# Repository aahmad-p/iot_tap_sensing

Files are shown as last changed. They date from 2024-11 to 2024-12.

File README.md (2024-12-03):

# _flomon_: A Water Tap Monitoring IoT System
This repository contains code and CAD (electrical and mechanical) files for _flomon_. This is a brief summary of the contents (by folder):
- ECAD: Contains electrical schematic and PCB layout files for custom sensor module (utilizing nRF52805 SoC for Bluetooth connectivity).
- Firmware: Contains firmware for sensor module (written in _C_).
- Gateway: Contains code for gateway (Raspberry Pi) interfacing with AWS IoT Core (written in _python_) .
- MCAD: Contains mechanical drawings for custom gateway and sensor housings (including custom adapter fittings).

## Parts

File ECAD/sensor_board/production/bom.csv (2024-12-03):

Comment | Designator | Footprint | LCSC Part Number
12pF C0G | C10, C9 | 402 | C1547
10uF | C11 | 805 | C15850
100nF | C2, C3 | 603 | C14663
5V | D1 | D_SOD-323 | C552583
S4B-XH-SM4-TB | J4 | CONN4_S4B-XH_JST | C161861
PMV48XP | Q2, Q3 | SOT-23 | C2959854
2N7002 | Q4 | SOT-23 | C916396
10R | R1 | 603 | C22859
100k | R12, R13 | 603 | C25803
330k | R2, R9 | 603 | C100970
22k | R6, R7 | 603 | C31850
TPL5111 | U1 | SOT-23-6 | C2870554
TPS22917DBV | U2 | SOT-23-6 | C2681320
32.768kHz | Y1 | Crystal_SMD_3215-2Pin_3.2x1.5mm | C32346

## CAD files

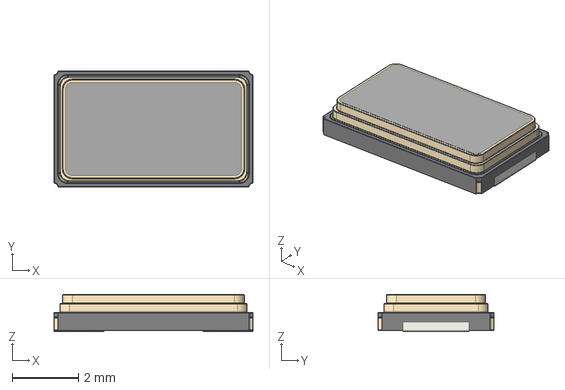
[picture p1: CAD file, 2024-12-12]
ECAD/sensor_board/3D/Crystal_SMD_0603-2Pin_6.0x3.5mm.step
6.00 x 3.50 x 1.13 mm

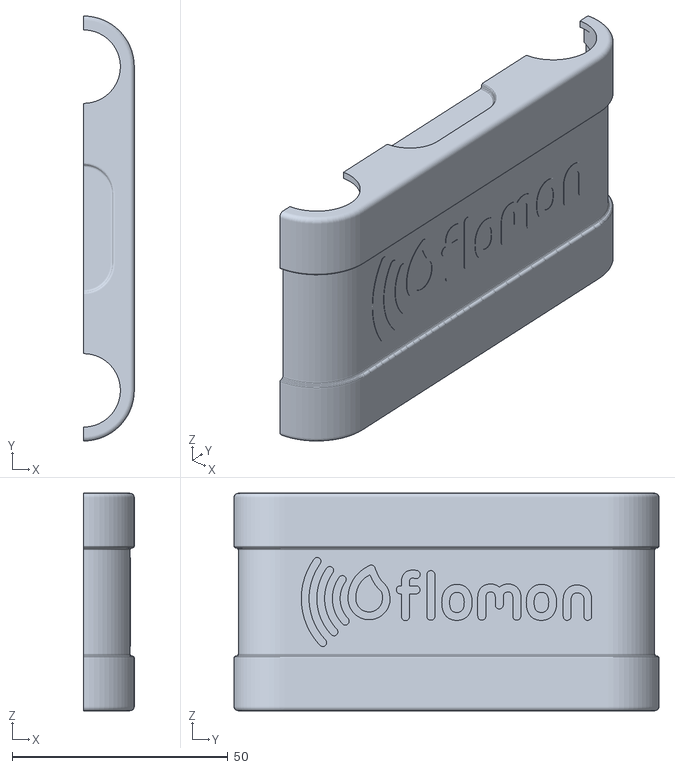
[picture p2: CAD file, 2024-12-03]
MCAD/FM-001A-Sensor-Top.stl
11.7 x 98.5 x 50.4

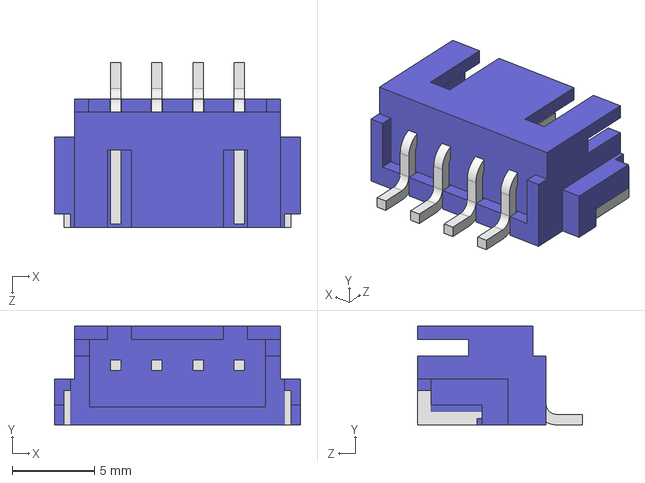
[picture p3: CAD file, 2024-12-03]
ECAD/sensor_board/3D/S4B-XH-SM4-TB.STEP
15.0 x 6.00 x 10.0 mm

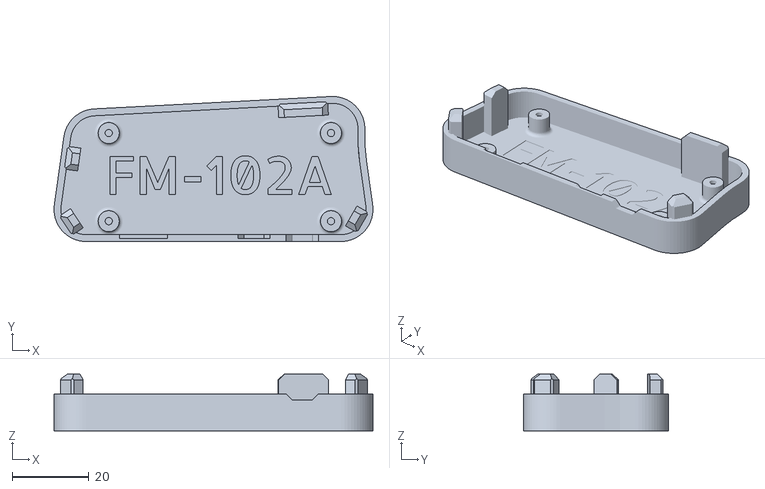
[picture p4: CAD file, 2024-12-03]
MCAD/FM-102A-Gateway-Bottom.stl
83.2 x 37.8 x 14.8

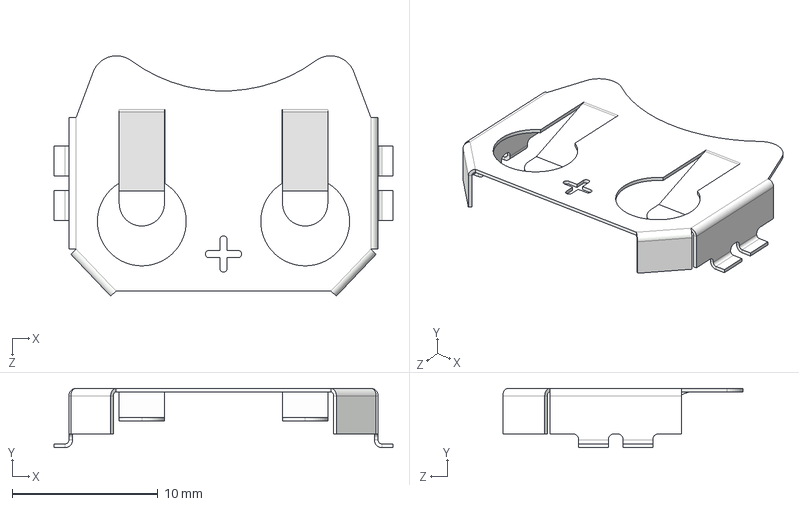
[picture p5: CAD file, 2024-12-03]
ECAD/sensor_board/3D/3034.step
23.2 x 4.06 x 16.5 mm

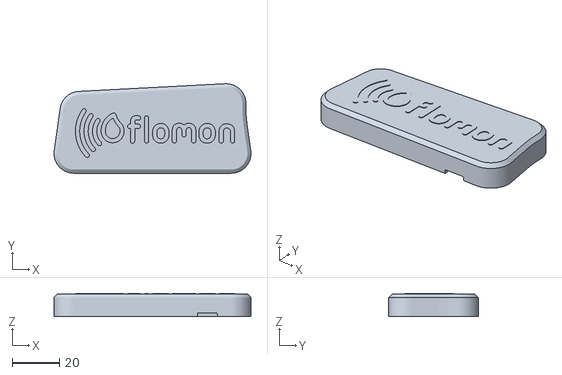
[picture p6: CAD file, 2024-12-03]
MCAD/FM-101A-Gateway-Top.stl
83.2 x 37.8 x 9.83

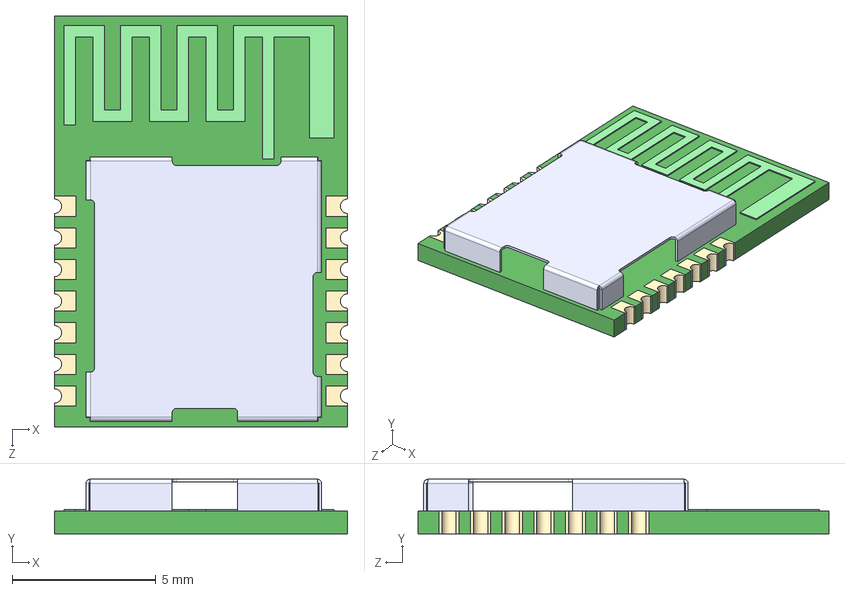
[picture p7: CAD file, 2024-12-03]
ECAD/sensor_board/3D/BC805M--3DModel-STEP-56544.STEP
10.2 x 1.90 x 14.3 mm

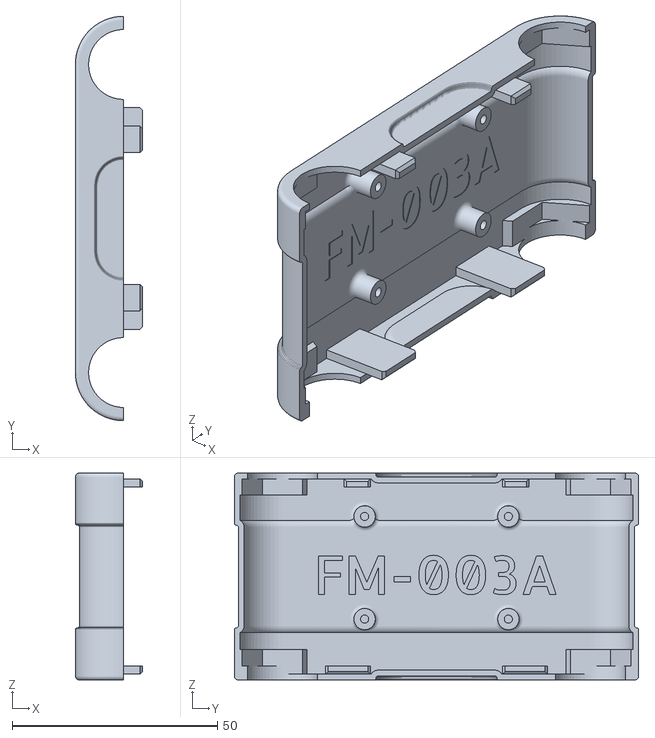
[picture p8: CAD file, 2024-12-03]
MCAD/FM-003A-Sensor-Bottom.stl
16.4 x 98.5 x 50.4

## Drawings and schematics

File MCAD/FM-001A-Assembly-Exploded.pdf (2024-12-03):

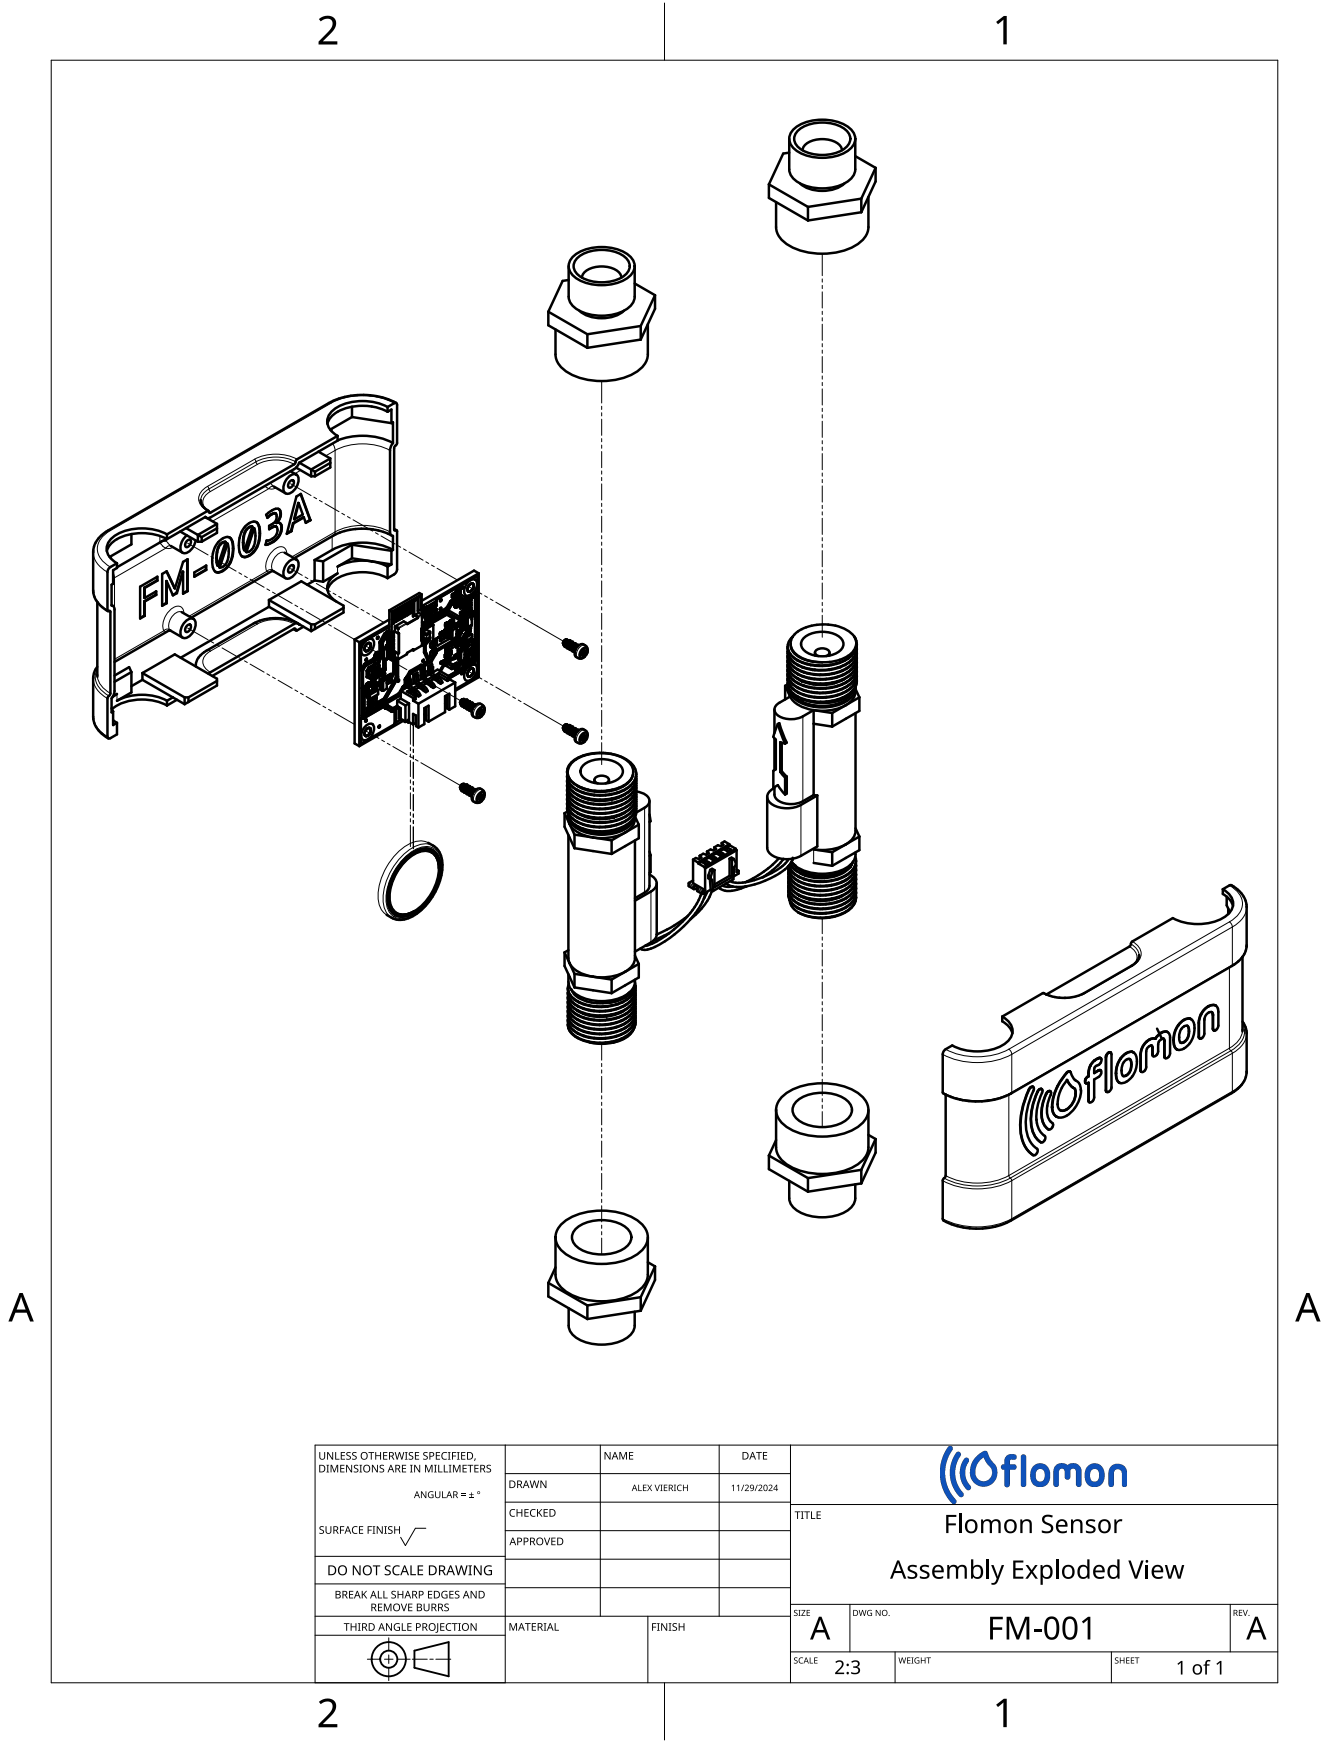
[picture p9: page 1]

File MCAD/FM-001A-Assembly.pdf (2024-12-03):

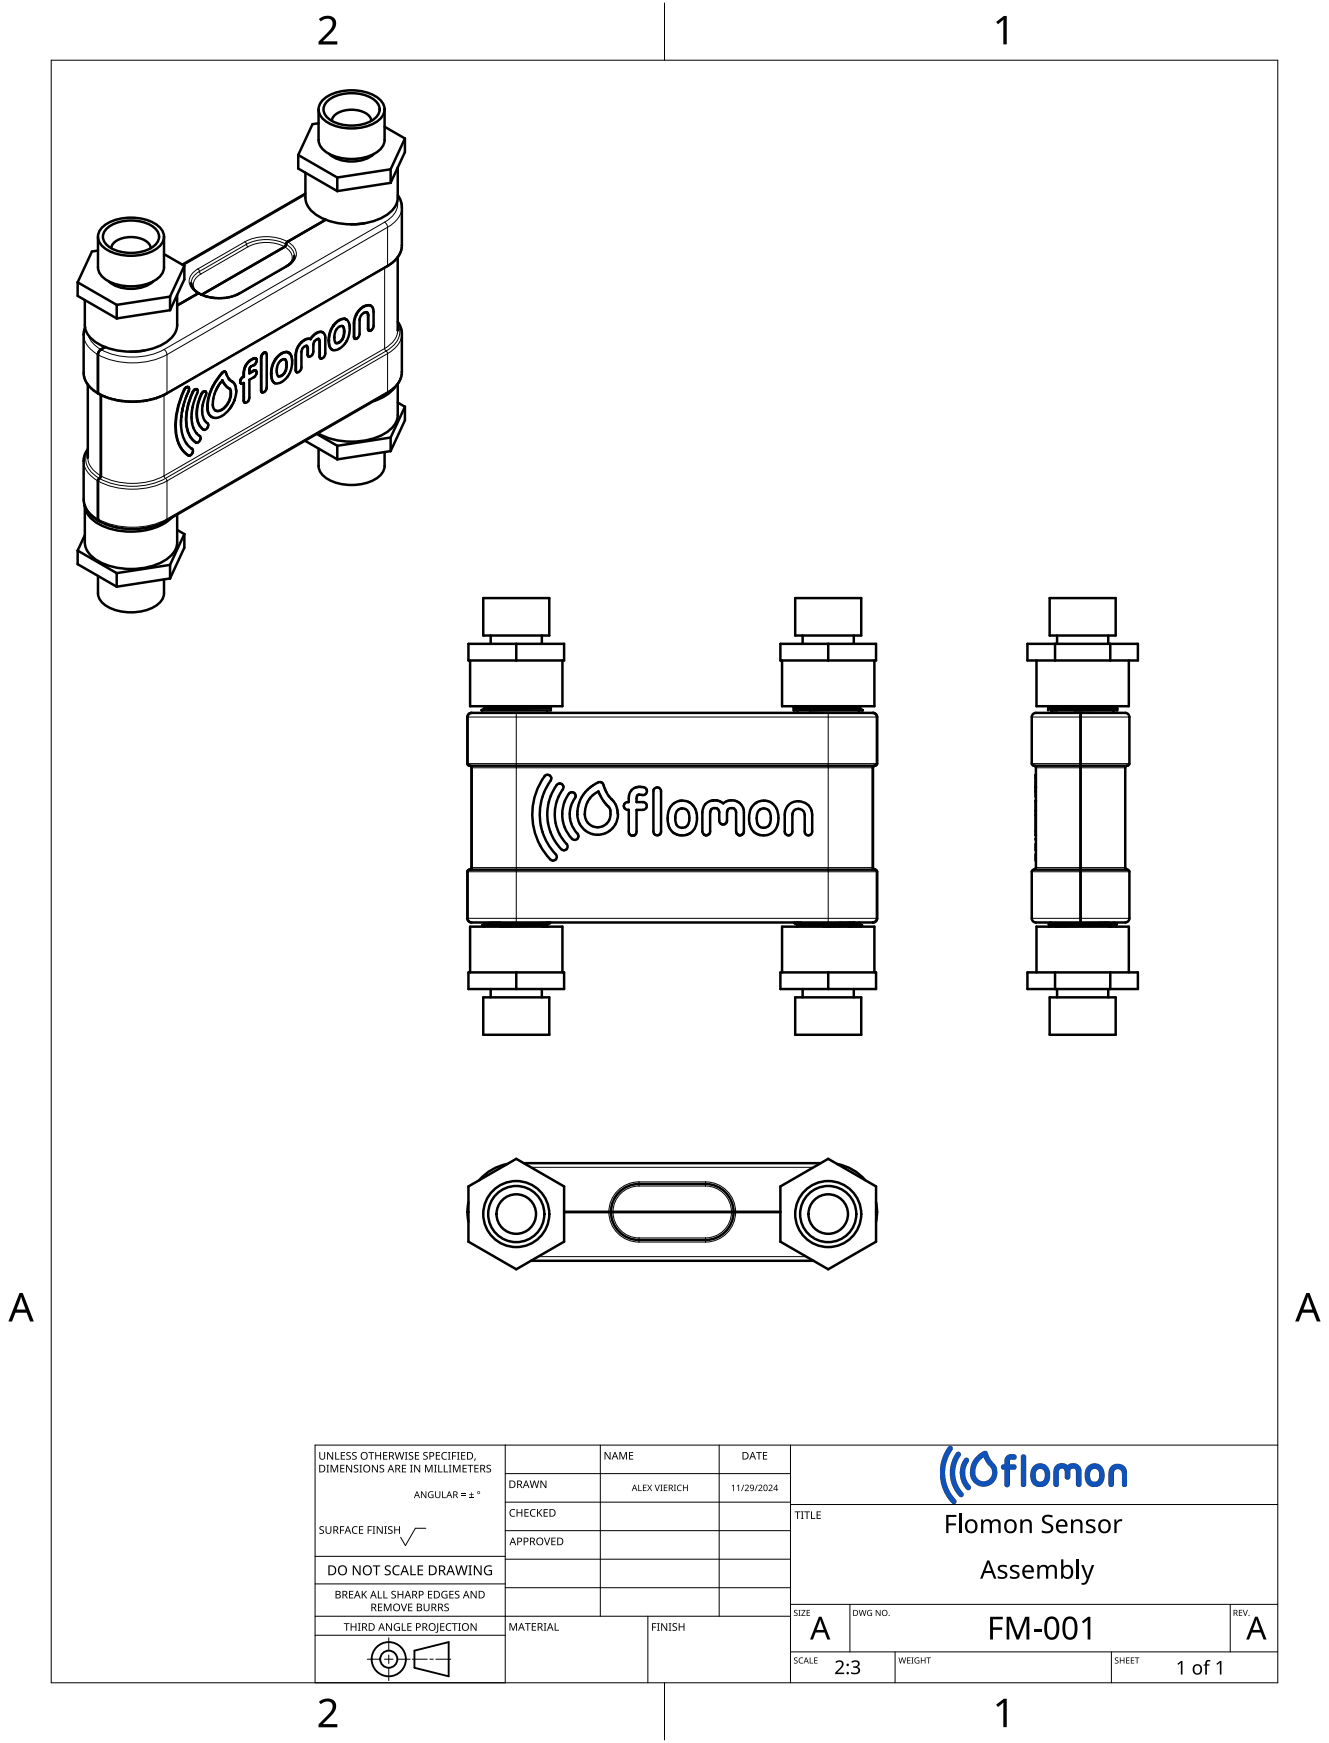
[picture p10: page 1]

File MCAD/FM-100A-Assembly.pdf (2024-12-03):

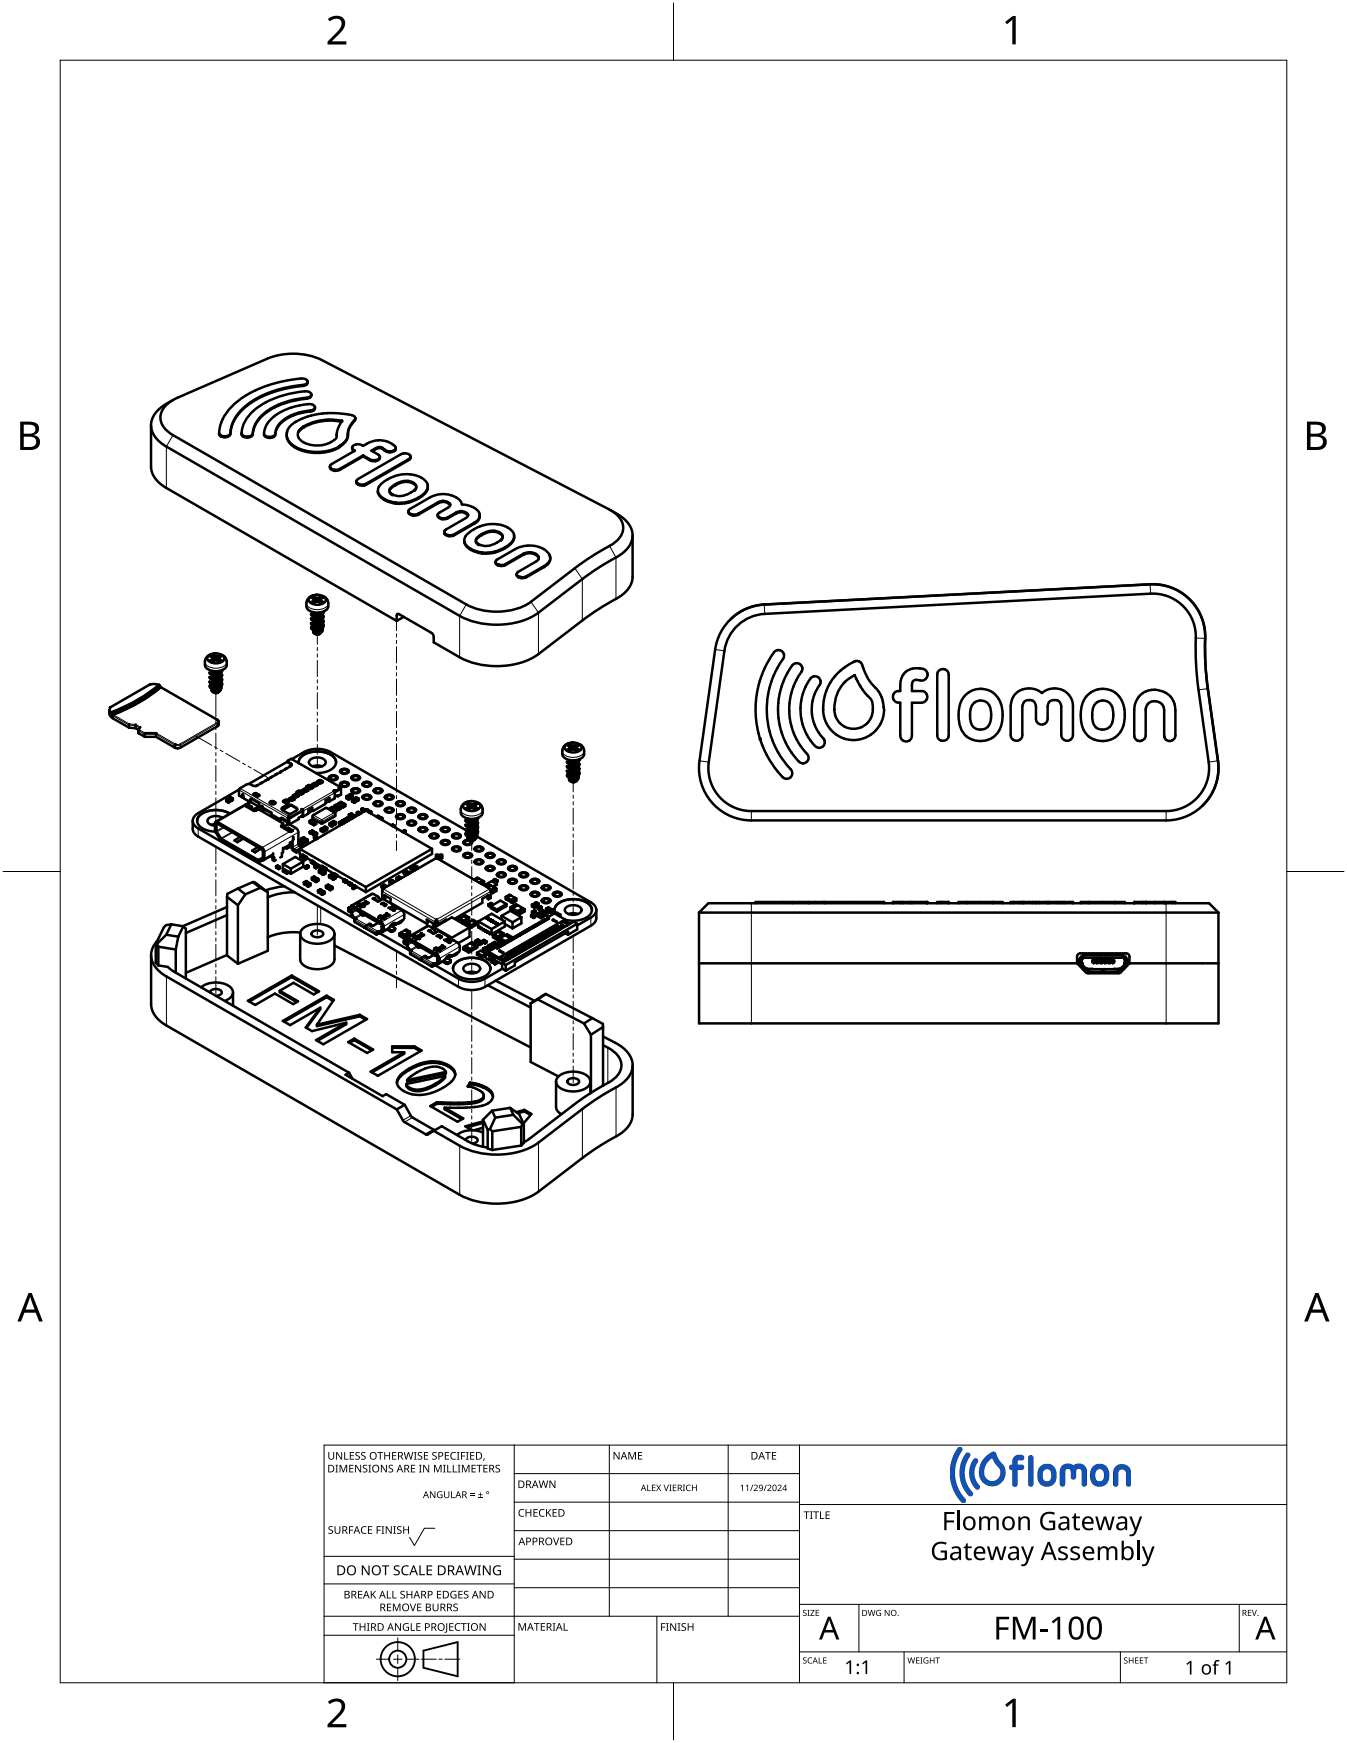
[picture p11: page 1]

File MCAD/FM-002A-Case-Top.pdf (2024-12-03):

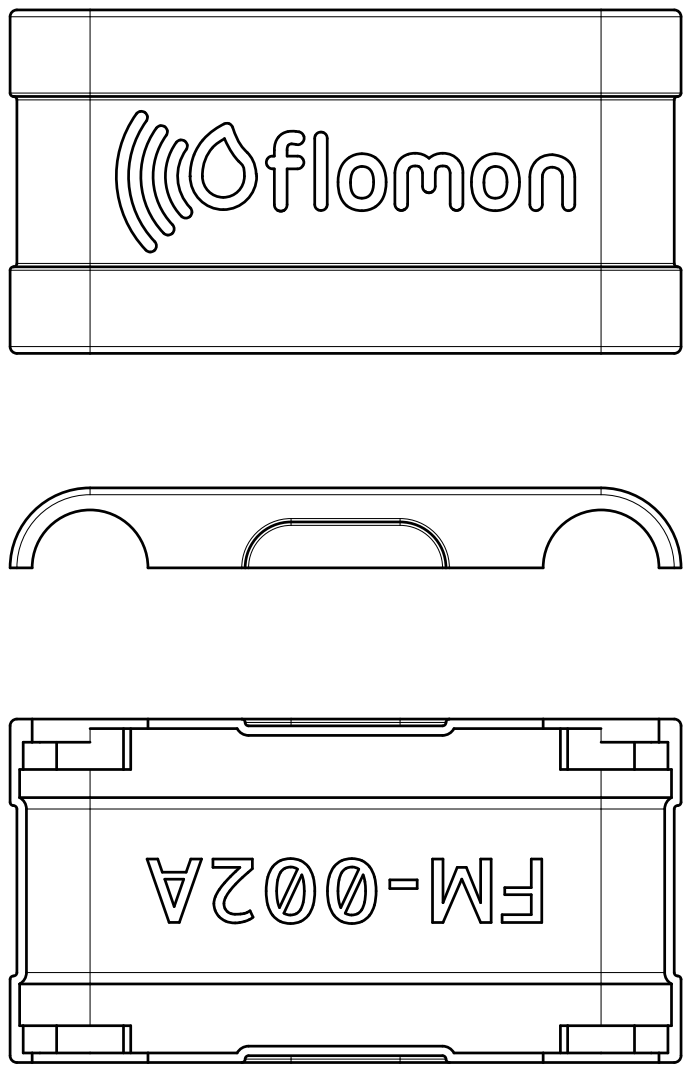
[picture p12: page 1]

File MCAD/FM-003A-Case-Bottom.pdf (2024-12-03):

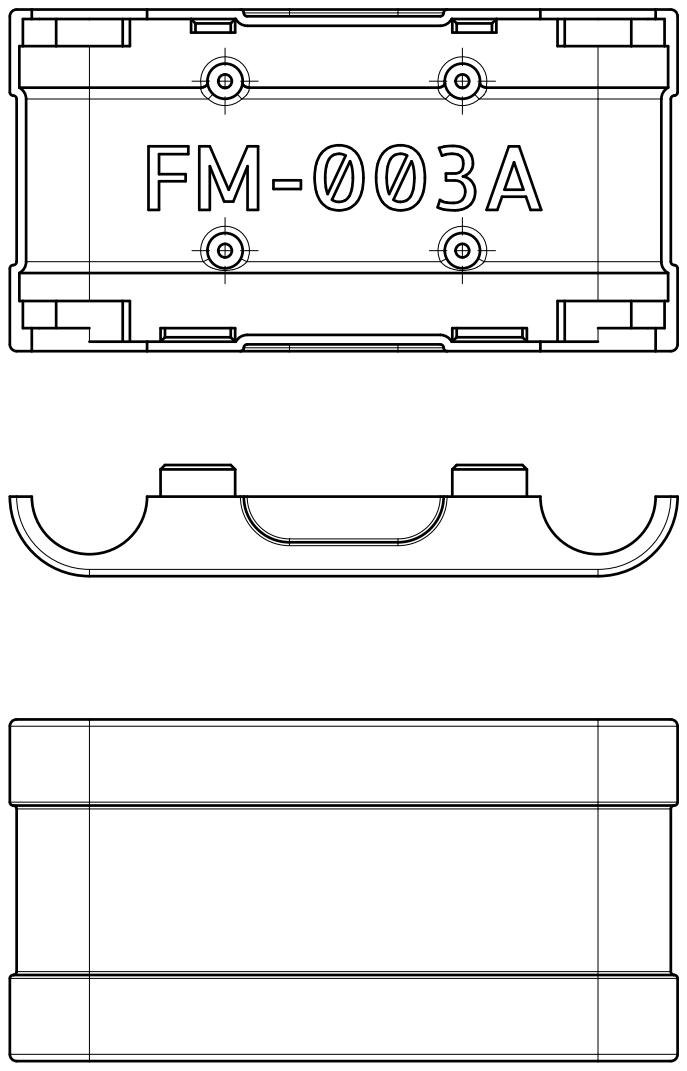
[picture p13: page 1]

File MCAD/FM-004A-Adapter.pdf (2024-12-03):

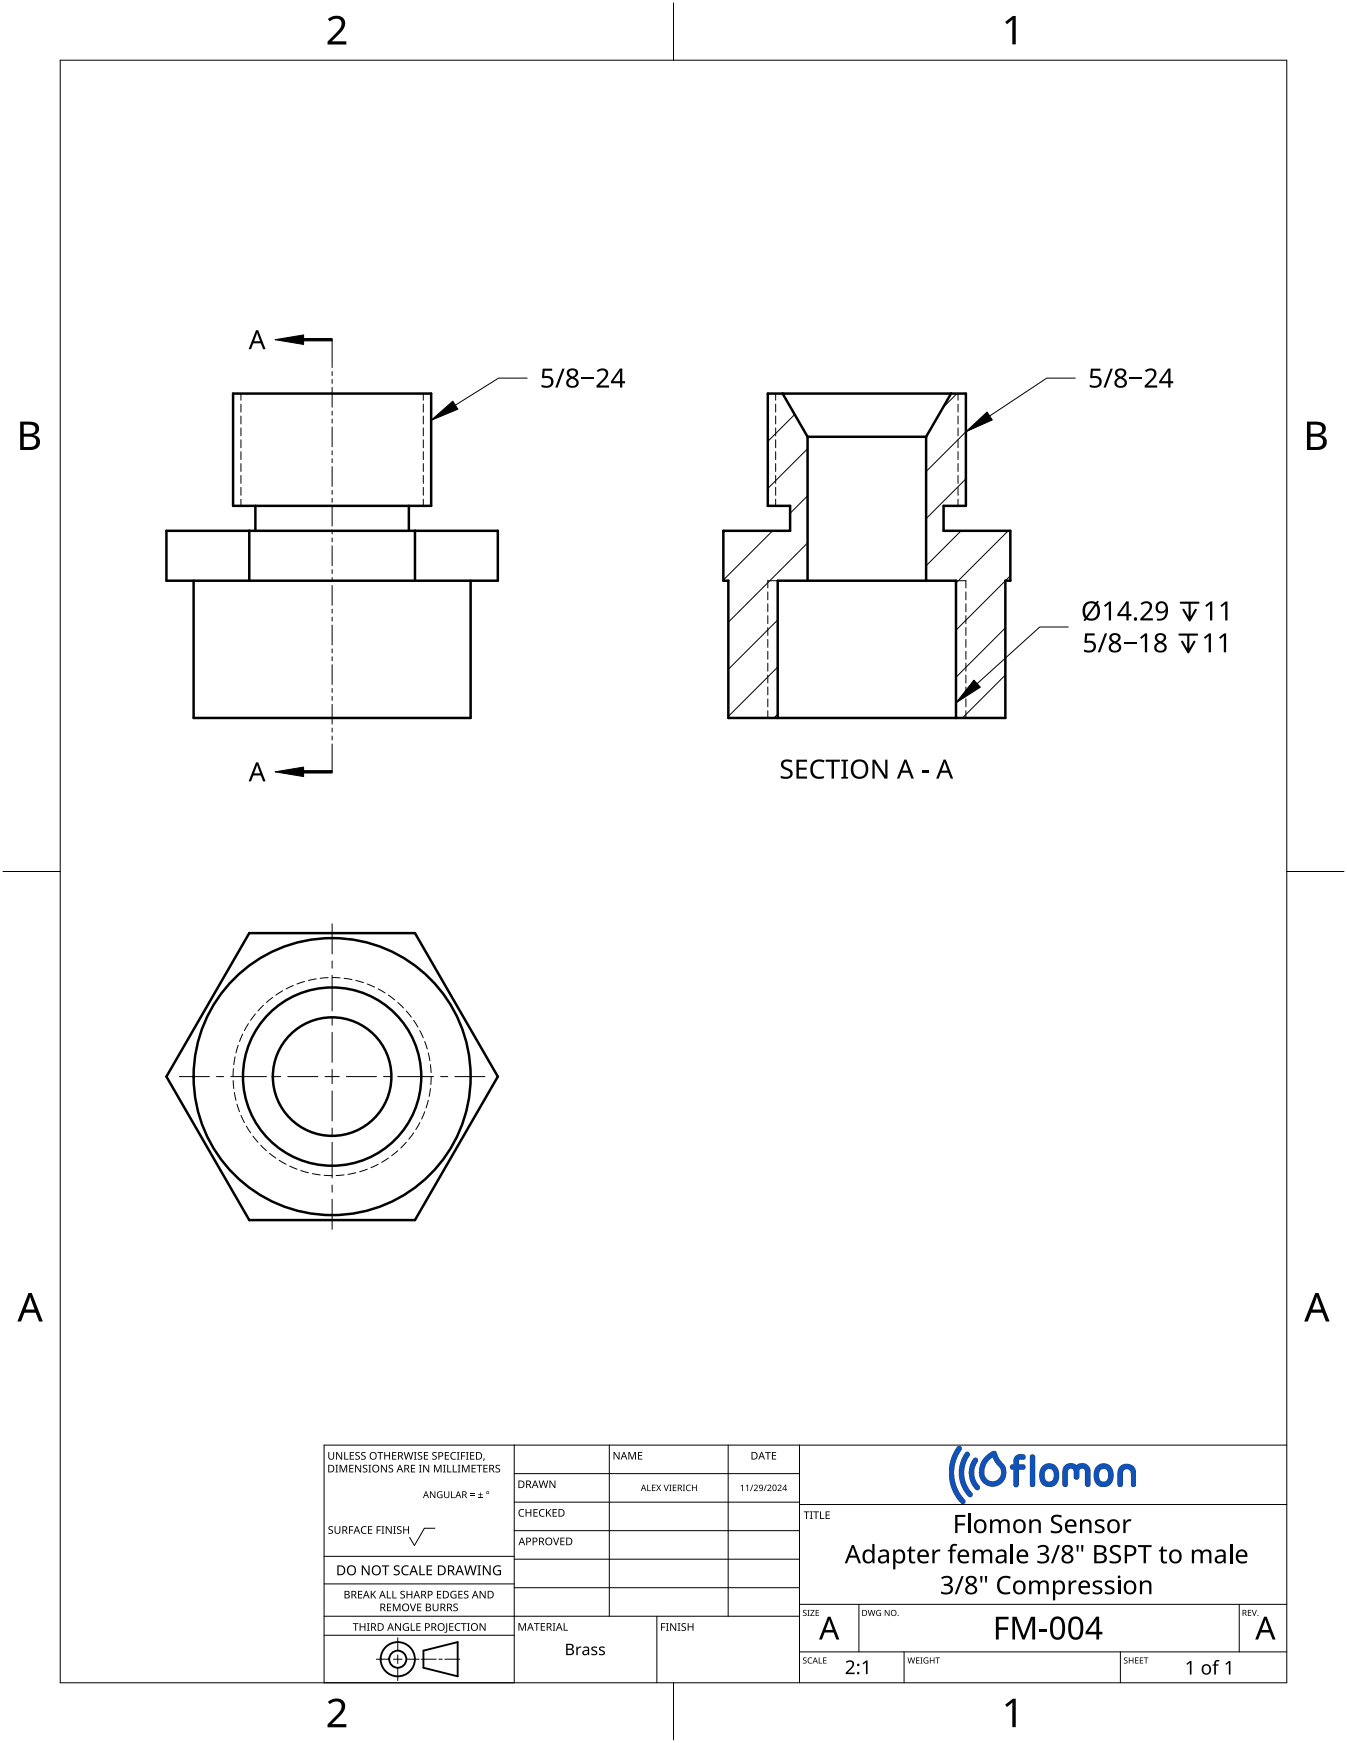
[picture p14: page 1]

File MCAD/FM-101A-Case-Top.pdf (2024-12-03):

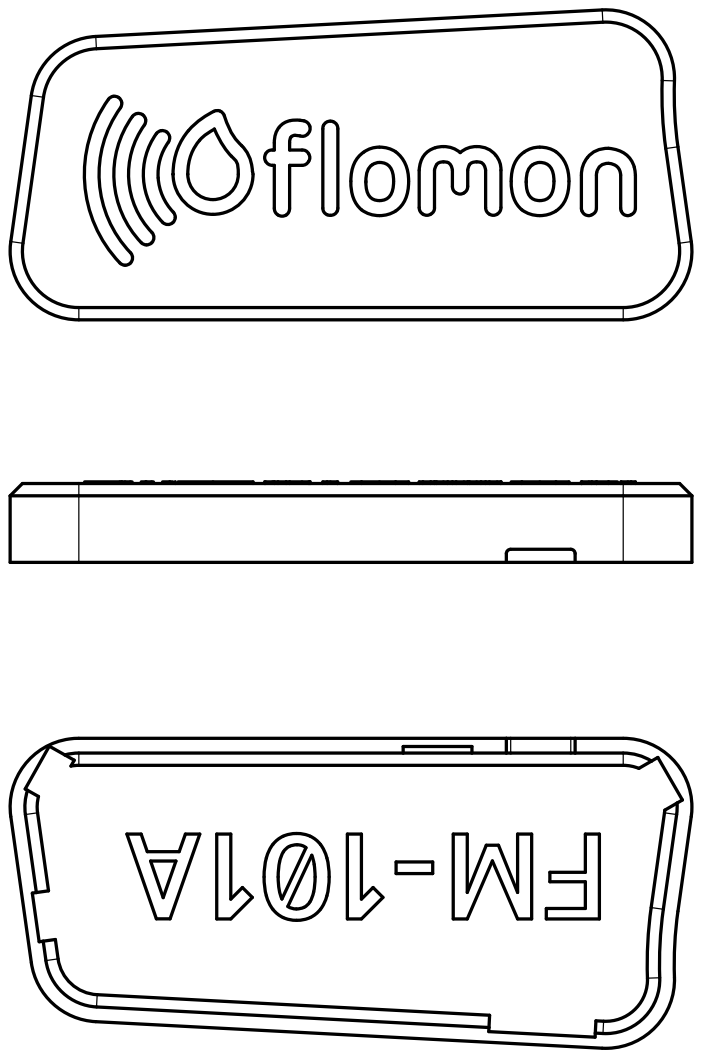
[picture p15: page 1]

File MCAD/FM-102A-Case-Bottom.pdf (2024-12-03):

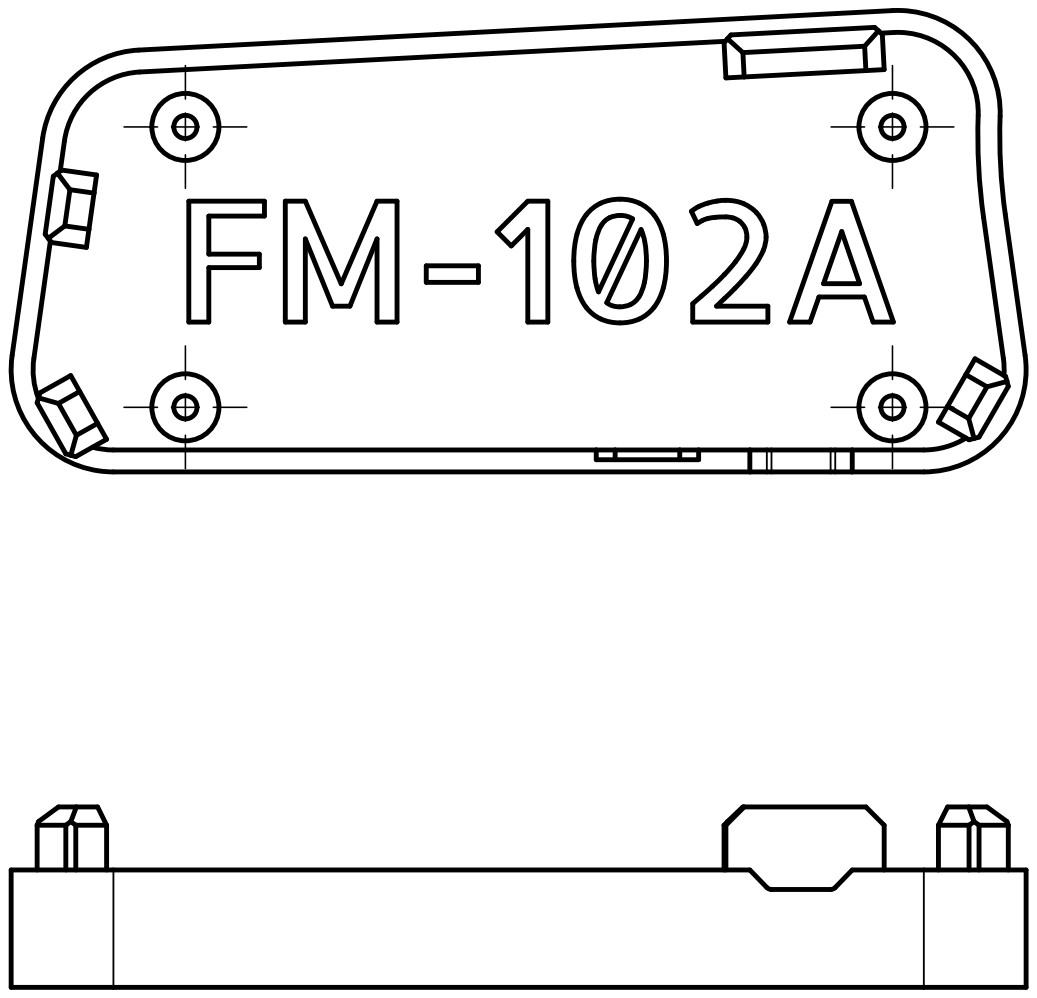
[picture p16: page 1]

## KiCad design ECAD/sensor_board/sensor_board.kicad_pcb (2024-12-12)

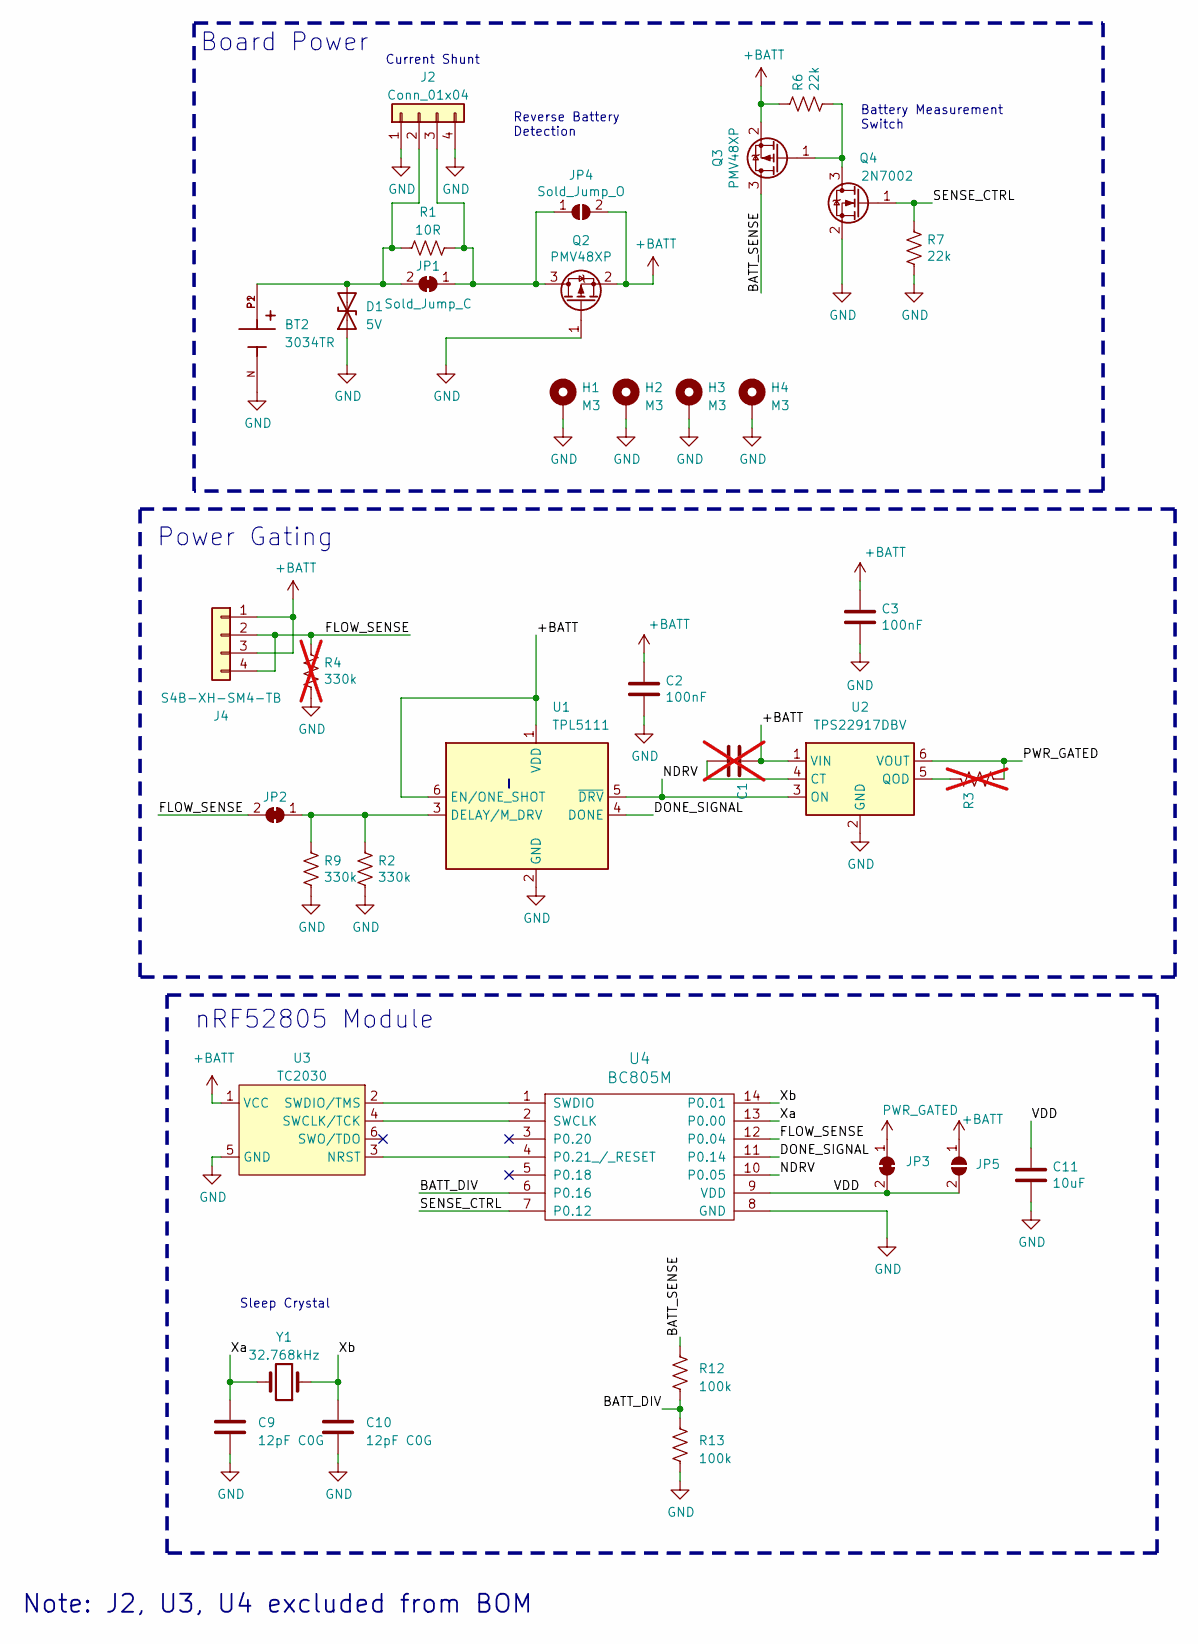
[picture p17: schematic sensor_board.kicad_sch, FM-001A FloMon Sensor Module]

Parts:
BT2: 3034TR; BAT_3034TR; PARTREV E; JLC C5213768
C1: C_0603_1608Metric; not fitted
C2, C3: 100nF; C_0603_1608Metric; MPN CC0603KRX7R9BB104; JLC C14663
C9, C10: 12pF C0G; C_0402_1005Metric; MPN 0402CG120J500NT; JLC C1547
C11: 10uF; C_0805_2012Metric; MPN CL21A106KAYNNNE; JLC C15850
D1: 5V; D_SOD-323; MPN PESD5V0V1BA,115; JLC C552583
H1, H2, H3, H4: M3; MountingHole_2.2mm_M2_Pad
J2: Conn_01x04; Test_Wire_Pad_x4
J4: S4B-XH-SM4-TB; CONN4_S4B-XH_JST; JLC C161861
JP1: Sold_Jump_C; SolderJumper-2_P1.3mm_Bridged_RoundedPad1.0x1.5mm
JP2, JP3: SolderJumper-2_P1.3mm_Bridged_RoundedPad1.0x1.5mm
JP4: Sold_Jump_O; SolderJumper-2_P1.3mm_Open_RoundedPad1.0x1.5mm
JP5: SolderJumper-2_P1.3mm_Open_RoundedPad1.0x1.5mm
Q2, Q3: PMV48XP; SOT-23; MPN PMV48XP; JLC C2959854
Q4: 2N7002; SOT-23; JLC C916396
R1: 10R; R_0603_1608Metric; MPN 0603WAF100JT5E; JLC C22859
R2, R9: 330k; R_0603_1608Metric; MPN CR0603FA3303G; JLC C100970
R3: R_0603_1608Metric; not fitted
R4: 330k; R_0603_1608Metric; MPN CR0603FA3303G; JLC C100970; not fitted
R6, R7: 22k; R_0603_1608Metric; MPN 0603WAF2202T5E; JLC C31850
R12, R13: 100k; R_0603_1608Metric; MPN 0603WAF1003T5E; JLC C25803
U1: TPL5111; SOT-23-6; JLC C2870554
U2: TPS22917DBV; SOT-23-6; JLC C2681320
U3: TC2030; TC2030-IDC-NL
U4: BC805M; BC805M_No_Paste
Y1: 32.768kHz; Crystal_SMD_3215-2Pin_3.2x1.5mm; MPN Q13FC1350000400; JLC C32346

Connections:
+BATT: C1.1, C2.1, C3.1, J4.1, J4.3, JP4.2 (B), JP5.1 (A), Q2.2 (S), Q3.2 (S), R6.1, U1.1 (VDD), U1.6 (EN/ONE_SHOT), U2.1 (VIN), U3.1 (VCC)
/BATT_DIV: R12.2, R13.1, U4.6 (P0.16)
/BATT_SENSE: Q3.3 (D), R12.1
/DONE_SIGNAL: U1.4 (DONE), U4.11 (P0.14)
/FLOW_SENSE: J4.2, J4.4, JP2.2 (B), R4.1, U4.12 (P0.04)
/NDRV: U1.5 (~DRV), U2.3 (ON), U4.10 (P0.05)
/SENSE_CTRL: Q4.1 (G), R7.1, U4.7 (P0.12)
/VDD: C11.1, JP3.2 (B), JP5.2 (B), U4.9 (VDD)
/Xa: C9.2, U4.13 (P0.00), Y1.2
/Xb: C10.2, U4.14 (P0.01), Y1.1
GND: BT2.N, C2.2, C3.2, C9.1, C10.1, C11.2, D1.1 (A1), H1.1, H2.1, H3.1, H4.1, J2.1, J2.4, Q2.1 (G), Q4.2 (S), R2.2, R4.2, R7.2, R9.2, R13.2, U1.2 (GND), U2.2 (GND), U3.5 (GND), U4.8 (GND)
unnamed: BT2.P1, BT2.P2, D1.2 (A2), J2.2, JP1.2 (B), R1.1
unnamed: J2.3, JP1.1 (A), JP4.1 (A), Q2.3 (D), R1.2
unnamed: JP2.1 (A), R2.1, R9.1, U1.3 (DELAY/M_DRV)
unnamed: Q3.1 (G), Q4.3 (D), R6.2
unnamed: C1.2, U2.4 (CT)
unnamed: R3.1, U2.5 (QOD)
unnamed: U3.3 (NRST), U4.4 (P0.21_/_RESET)
unnamed: U3.4 (SWCLK/TCK), U4.2 (SWCLK)
unnamed: U3.2 (SWDIO/TMS), U4.1 (SWDIO)
PWR_GATED: JP3.1 (A), R3.2, U2.6 (VOUT)

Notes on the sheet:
Power Gating
Battery Measurement Switch
Sleep Crystal
Note: J2, U3, U4 excluded from BOM
Current Shunt
Board Power
Reverse Battery Detection
nRF52805 Module

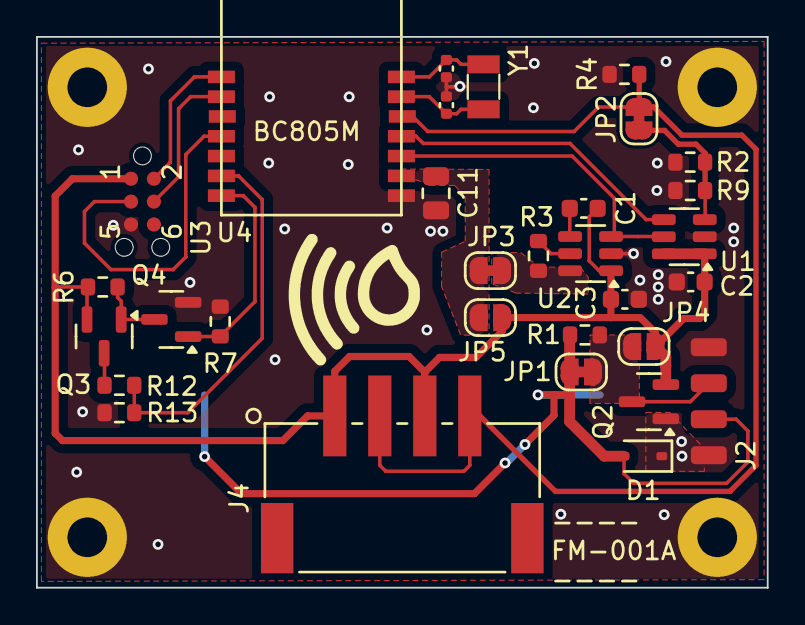
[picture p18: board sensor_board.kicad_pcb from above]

Board: 2 copper layers, 40.6 x 30.6 mm, 36 parts (1 on the bottom side), 21 nets.

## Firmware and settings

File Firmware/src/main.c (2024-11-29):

/*
 * Copyright (c) 2023 Nordic Semiconductor ASA
 *
 * SPDX-License-Identifier: Apache-2.0
 */

#include <zephyr/bluetooth/bluetooth.h>
#include <zephyr/bluetooth/uuid.h>
#include <zephyr/drivers/gpio.h>

#define SERVICE_DATA_LEN        7
#define SERVICE_UUID            0xfcd2      /* BTHome service UUID */
#define IDX_RUNNING               4           /* Index of byte of running in service data*/
#define IDX_WATCHDOG              6           /* Index of byte of watchdog in service data*/

#define ADV_PARAM BT_LE_ADV_PARAM(BT_LE_ADV_OPT_USE_IDENTITY, \
				  BT_GAP_ADV_SLOW_INT_MIN, \
				  BT_GAP_ADV_SLOW_INT_MAX, NULL)


#define MAX_OFF_PERIODS           20 

static const struct gpio_dt_spec pm_done = GPIO_DT_SPEC_GET(DT_NODELABEL(pm_done), gpios);
static const struct gpio_dt_spec button = GPIO_DT_SPEC_GET(DT_NODELABEL(button), gpios);


static uint8_t service_data[SERVICE_DATA_LEN] = {
	BT_UUID_16_ENCODE(SERVICE_UUID),
	0x40,
	0x27,	/* Running */
	0x00,	/* Off Byte */
	0x0F,   /* Generic Boolean (watchdog) */
	0x00    /* Watchdog Byte */
};

static struct bt_data ad[] = {
	BT_DATA_BYTES(BT_DATA_FLAGS, BT_LE_AD_GENERAL | BT_LE_AD_NO_BREDR),
	BT_DATA(BT_DATA_NAME_COMPLETE, CONFIG_BT_DEVICE_NAME, sizeof(CONFIG_BT_DEVICE_NAME) - 1),
	BT_DATA(BT_DATA_SVC_DATA16, service_data, ARRAY_SIZE(service_data))
};

static void bt_ready(int err)
{
	if (err) {
		printk("Bluetooth init failed (err %d)\n", err);
		return;
	}

	printk("Bluetooth initialized\n");

	/* Start advertising */
	err = bt_le_adv_start(ADV_PARAM, ad, ARRAY_SIZE(ad), NULL, 0);
	if (err) {
		printk("Advertising failed to start (err %d)\n", err);
		return;
	}
}

int main(void)
{
	int err;
	int ret;
	int off_periods = 0;

	printk("Sensor Starting\n");

	/* Initialize Peripherals */

	if(!device_is_ready(button.port)){
		return 0;
	}

	/* Initialize the Bluetooth Subsystem */
	err = bt_enable(bt_ready);
	if (err) {
		printk("Bluetooth init failed (err %d)\n", err);
		return 0;
	}

	err = gpio_pin_configure_dt(&pm_done, GPIO_OUTPUT_LOW);
        if (err) {
		return 0;
	}

	err = gpio_pin_configure_dt(&button, GPIO_INPUT);
        if (err) {
		return 0;
	}

	/* Startup State:
	 * Check if flow sensor woke device */

	// Poll flow switch several times
	for (int i = 0; i < 3; i++) {
		ret = gpio_pin_get_dt(&button);
		if (ret == 1) {
			off_periods++;
		} else if (ret != 0) {
			return 0;
		}
		k_sleep(K_MSEC(50));
	}

	if (off_periods == 0) {
		// This is a watchdog wake
		service_data[IDX_WATCHDOG] = 0x01;
	}

	for (;;) {
		ret = gpio_pin_get_dt(&button);
		if (ret == 1) {
			service_data[IDX_RUNNING] = 0x01;
			service_data[IDX_WATCHDOG] = 0x00;
			off_periods = 0;
		} else if (ret == 0) {
			service_data[IDX_RUNNING] = 0x00;
			off_periods++;
		} else {
			return 0;
		}
		err = bt_le_adv_update_data(ad, ARRAY_SIZE(ad), NULL, 0);
		if (err) {
			printk("Failed to update advertising data (err %d)\n", err);
		}

		// Tap has been checked to be off long enough, tap is either turned off or this is a watchdog.
		if (off_periods == MAX_OFF_PERIODS) {
			// Switch off the power rail
			err = gpio_pin_set_dt(&pm_done, 1);
		}

		k_sleep(K_MSEC(BT_GAP_ADV_SLOW_INT_MIN));
	}
	return 0;
}

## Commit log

2024-11-02 Adding schematic starting point for sensor
    [iot_tap_sensor.kicad_pcb, iot_tap_sensor.kicad_sch]
2024-11-06 Pushing sensor board schematic (in progress)
    [sensor_board.kicad_sch]
2024-11-06 Pushing updates to schematic
    [sensor_board.kicad_sch]
2024-11-07 Format and adding footprints
    [3034.step, S4B-XH-SM4-TB.STEP, sensor_board.kicad_sch]
2024-11-07 PCB Editor updates: updated settings (e.g. Design Rules under Board Setup), added footprints to library, added parts to PCB
    [sensor_board.kicad_pcb, sensor_board.kicad_sch]
2024-11-11 Initial version of routed board
    [BC805M--3DModel-STEP-56544.STEP, sensor_board.kicad_pcb]
2024-11-12 Updated board layout
    [sensor_board.kicad_pcb, sensor_board.kicad_sch]
2024-11-12 Additional minor changes to layout
    [sensor_board.kicad_pcb]
2024-11-13 Pushing completed layout
    [sensor_board.kicad_pcb, sensor_board.kicad_sch]
2024-11-21 Adding prototype BLE adv recieving code
2024-11-21 Pushing production files and other changes (board has arrived)
    [bom.csv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]
2024-12-03 Adding CAD outputs
    [FM-001A-Sensor-Top.stl, FM-003A-Sensor-Bottom.stl, FM-101A-Gateway-Top.stl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]
2024-12-04 Removed old ECAD project files
    [iot_tap_sensor.kicad_pcb, iot_tap_sensor.kicad_sch]
2024-12-12 Adding XTAL datasheet and 3D model
    [Crystal_SMD_0603-2Pin_6.0x3.5mm.step, sensor_board.kicad_pcb, sensor_board.kicad_sch]

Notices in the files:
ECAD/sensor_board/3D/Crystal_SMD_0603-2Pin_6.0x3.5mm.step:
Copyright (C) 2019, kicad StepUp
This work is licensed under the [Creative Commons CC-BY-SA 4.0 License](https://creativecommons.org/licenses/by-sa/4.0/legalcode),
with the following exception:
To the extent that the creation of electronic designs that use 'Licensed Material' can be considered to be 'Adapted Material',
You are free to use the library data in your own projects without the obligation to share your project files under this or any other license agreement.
